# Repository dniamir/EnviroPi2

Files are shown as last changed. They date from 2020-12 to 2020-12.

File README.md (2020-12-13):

# EnvriPi sensor hub shield for Raspberry Pi
A Raspberry Pi shield that houses several different types of sensors
-BME280 - Bosch pressure, temperature and humidity sensor
-BME680 - Bosch pressure, humidity, temperature and VOC sensor
-TMP102 - Texas Instruments temperature sensor
-BMM150 - Bosch magnetometer
-TSL25911FN - Light intensity sensor
-ICM-20649 - Invensense 6-axis IMU (3-axis gyroscope and 3-axis accelerometer)

## Summary
This code utlizies high level functions to communicate with sensors and set their configuration for proper monitoring of an aquarium.

Unfortunately, I can't make the sub-repository for chip communication public. However that package provides a simple interface for communicating with sensors va I2C and SPI.

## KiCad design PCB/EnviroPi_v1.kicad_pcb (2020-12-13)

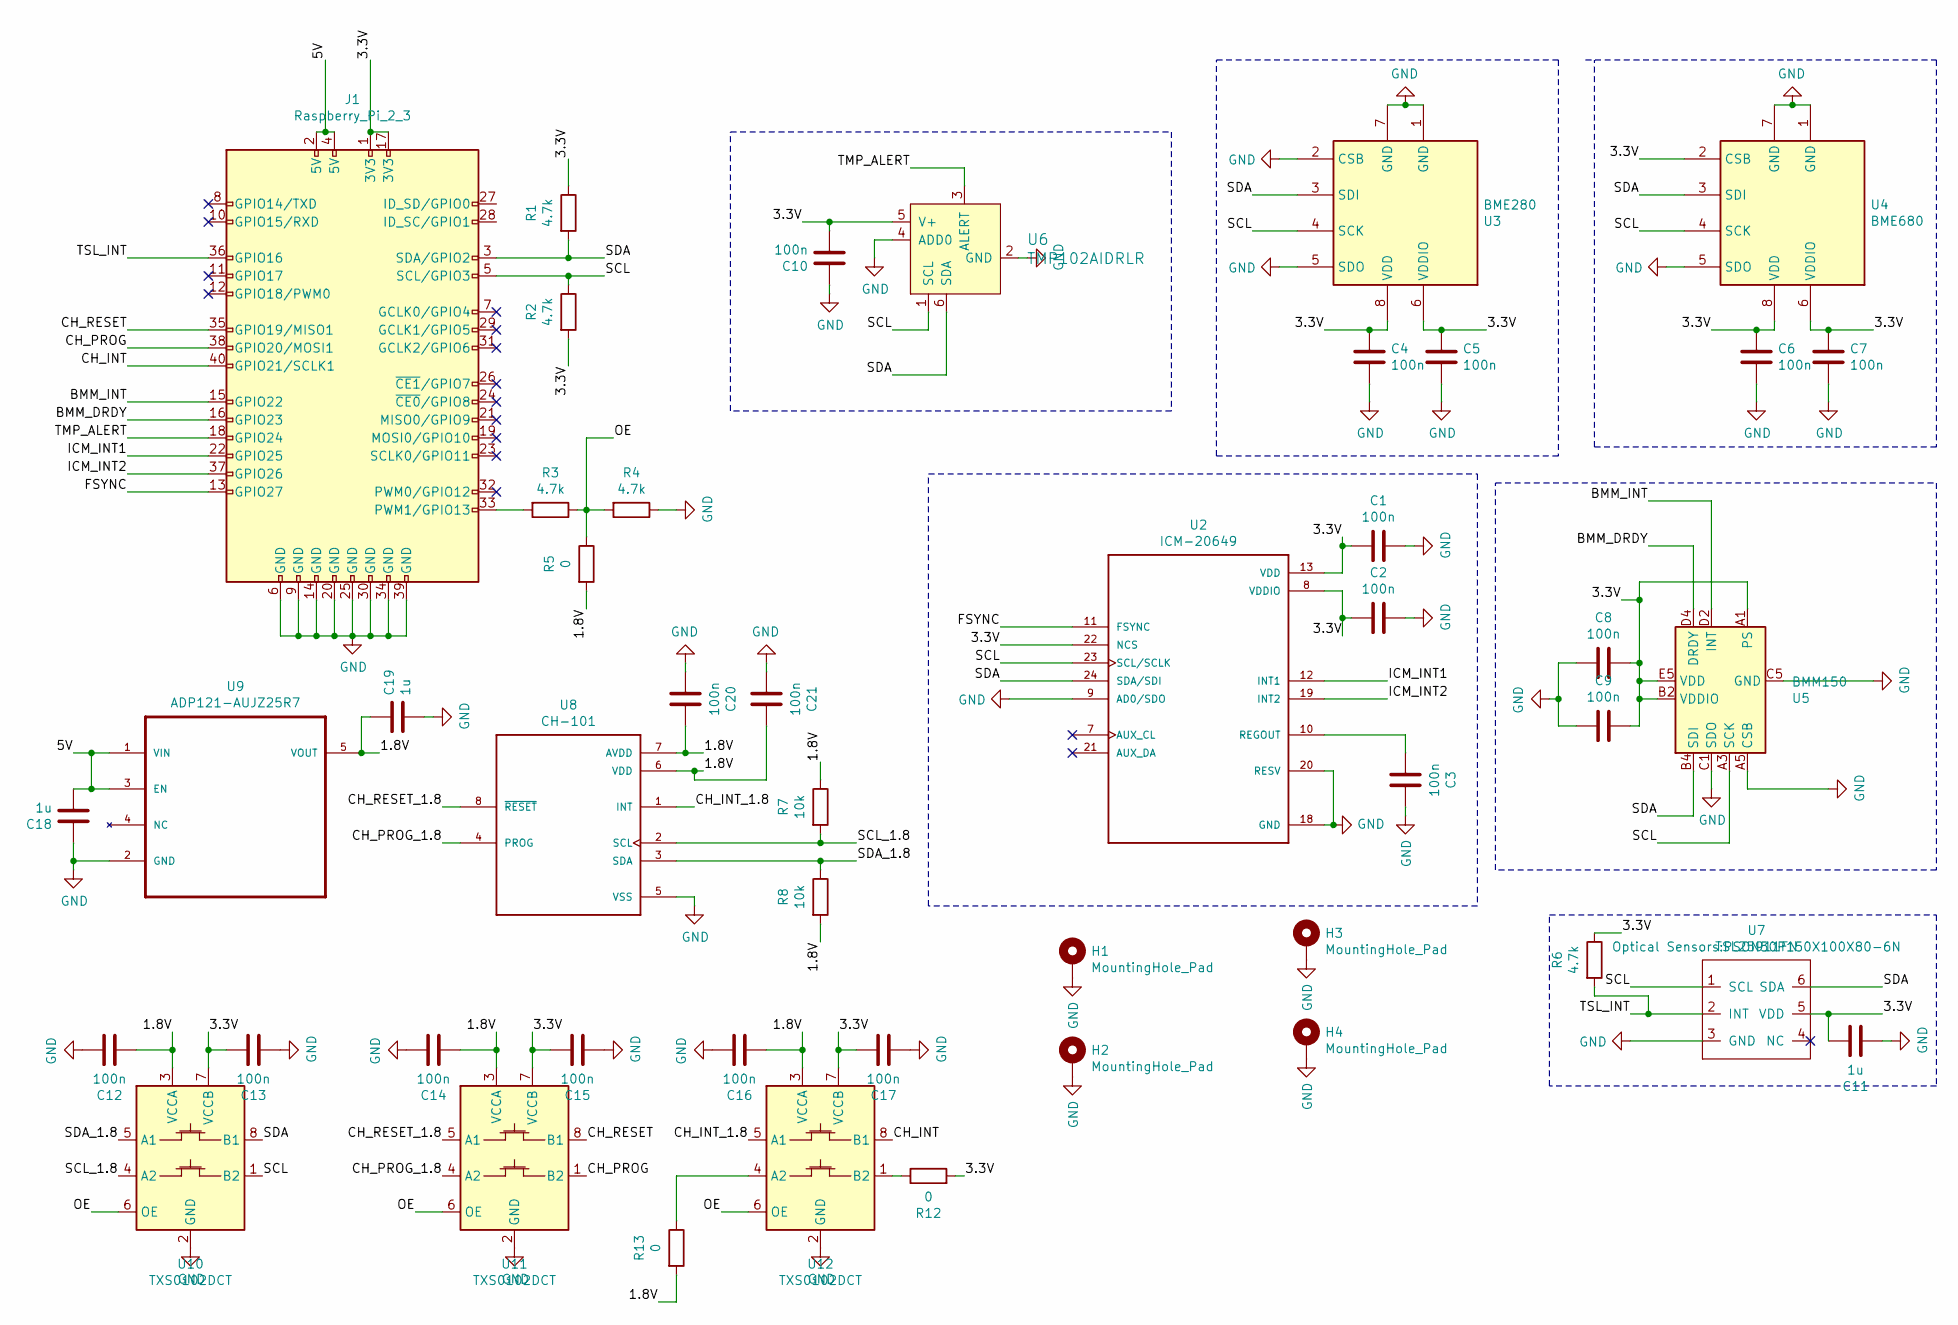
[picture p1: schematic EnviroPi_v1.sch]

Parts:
C1, C2, C3, C4, C5, C6, C7, C8, C9, C10, C12, C13, C14, C15, C16, C17, C20, C21: 100n; C_0805_2012Metric_Pad1.15x1.40mm_HandSolder
C11, C18, C19: 1u; C_0805_2012Metric_Pad1.15x1.40mm_HandSolder
H1, H2, H3, H4: MountingHole_Pad; MountingHole_2.5mm_Pad
J1: Raspberry_Pi_2_3; PinHeader_2x20_P2.54mm_Vertical
R1, R2, R3, R4, R6: 4.7k; R_0805_2012Metric_Pad1.15x1.40mm_HandSolder
R5, R12, R13: 0; R_0805_2012Metric_Pad1.15x1.40mm_HandSolder
R7, R8: 10k; R_0805_2012Metric_Pad1.15x1.40mm_HandSolder
U2: ICM-20649; QFN40P300X300X95-24N
U3: BME280; Bosch_LGA-8_2.5x2.5mm_P0.65mm_ClockwisePinNumbering
U4: BME680; Bosch_LGA-8_3x3mm_P0.8mm_ClockwisePinNumbering
U5: BMM150; WLCSP-12_1.56x1.56mm_P0.4mm
U6: TMP102AIDRLR; SOT50P160X60-6N; MPN TMP102AIDRLR; Digi-Key_PN 296-26834-1-ND
U7: TSL25911FN; PSON50P150X100X80-6N
U8: CH-101; XDCR_CH-101
U9: ADP121-AUJZ25R7; SOT95P280X100-5N
U10, U11, U12: TXS0102DCT; SSOP-8_2.95x2.8mm_P0.65mm

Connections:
/1.8V: C12.1, C14.1, C16.1, C19.1, C20.2, C21.2, R5.2, R7.1, R8.2, R13.2, U8.6 (VDD), U8.7 (AVDD), U9.5 (VOUT), U10.3 (VCCA), U11.3 (VCCA), U12.3 (VCCA)
/3.3V: C1.1, C2.1, C4.1, C5.1, C6.1, C7.1, C8.2, C9.2, C10.2, C11.2, C13.2, C15.2, C17.2, J1.1 (3V3), J1.17 (3V3), R1.1, R2.2, R6.1, R12.2, U2.8 (VDDIO), U2.13 (VDD), U2.22 (NCS), U3.6 (VDDIO), U3.8 (VDD), U4.2 (CSB), U4.6 (VDDIO), U4.8 (VDD), U5.A1 (PS), U5.B2 (VDDIO), U5.E5 (VDD), U6.5 (V+), U7.5 (VDD), U10.7 (VCCB), U11.7 (VCCB), U12.7 (VCCB)
/5V: C18.2, J1.2 (5V), J1.4 (5V), U9.1 (VIN), U9.3 (EN)
/BMM_DRDY: J1.16 (GPIO23), U5.D4 (DRDY)
/BMM_INT: J1.15 (GPIO22), U5.D2 (INT)
/CH_INT: J1.40 (GPIO21/SCLK1), U12.8 (B1)
/CH_INT_1.8: U8.1 (INT), U12.5 (A1)
/CH_PROG: J1.38 (GPIO20/MOSI1), U11.1 (B2)
/CH_PROG_1.8: U8.4 (PROG), U11.4 (A2)
/CH_RESET: J1.35 (GPIO19/MISO1), U11.8 (B1)
/CH_RESET_1.8: U8.8 (~RESET~), U11.5 (A1)
/FSYNC: J1.13 (GPIO27), U2.11 (FSYNC)
/ICM_INT1: J1.22 (GPIO25), U2.12 (INT1)
/ICM_INT2: J1.37 (GPIO26), U2.19 (INT2)
/OE: R3.1, R4.2, R5.1, U10.6 (OE), U11.6 (OE), U12.6 (OE)
/SCL: J1.5 (SCL/GPIO3), R2.1, U2.23 (SCL/SCLK), U3.4 (SCK), U4.4 (SCK), U5.A3 (SCK), U6.1 (SCL), U7.1 (SCL), U10.1 (B2)
/SCL_1.8: R7.2, U8.2 (SCL), U10.4 (A2)
/SDA: J1.3 (SDA/GPIO2), R1.2, U2.24 (SDA/SDI), U3.3 (SDI), U4.3 (SDI), U5.B4 (SDI), U6.6 (SDA), U7.6 (SDA), U10.8 (B1)
/SDA_1.8: R8.1, U8.3 (SDA), U10.5 (A1)
/TMP_ALERT: J1.18 (GPIO24), U6.3 (ALERT)
/TSL_INT: J1.36 (GPIO16), R6.2, U7.2 (INT)
GND: C1.2, C2.2, C3.2, C4.2, C5.2, C6.2, C7.2, C8.1, C9.1, C10.1, C11.1, C12.2, C13.1, C14.2, C15.1, C16.2, C17.1, C18.1, C19.2, C20.1, C21.1, H1.1, H2.1, H3.1, H4.1, J1.6 (GND), J1.9 (GND), J1.14 (GND), J1.20 (GND), J1.25 (GND), J1.30 (GND), J1.34 (GND), J1.39 (GND), R4.1, U2.9 (AD0/SDO), U2.18 (GND), U2.20 (RESV), U3.1 (GND), U3.2 (CSB), U3.5 (SDO), U3.7 (GND), U4.1 (GND), U4.5 (SDO), U4.7 (GND), U5.A5 (CSB), U5.C1 (SDO), U5.C5 (GND), U5.E1 (GND), U5.E3 (GND), U6.2 (GND), U6.4 (ADD0), U7.3 (GND), U8.5 (VSS), U9.2 (GND), U10.2 (GND), U11.2 (GND), U12.2 (GND)
unnamed: C3.1, U2.10 (REGOUT)
unnamed: J1.33 (PWM1/GPIO13), R3.2
unnamed: R12.1, U12.1 (B2)
unnamed: R13.1, U12.4 (A2)

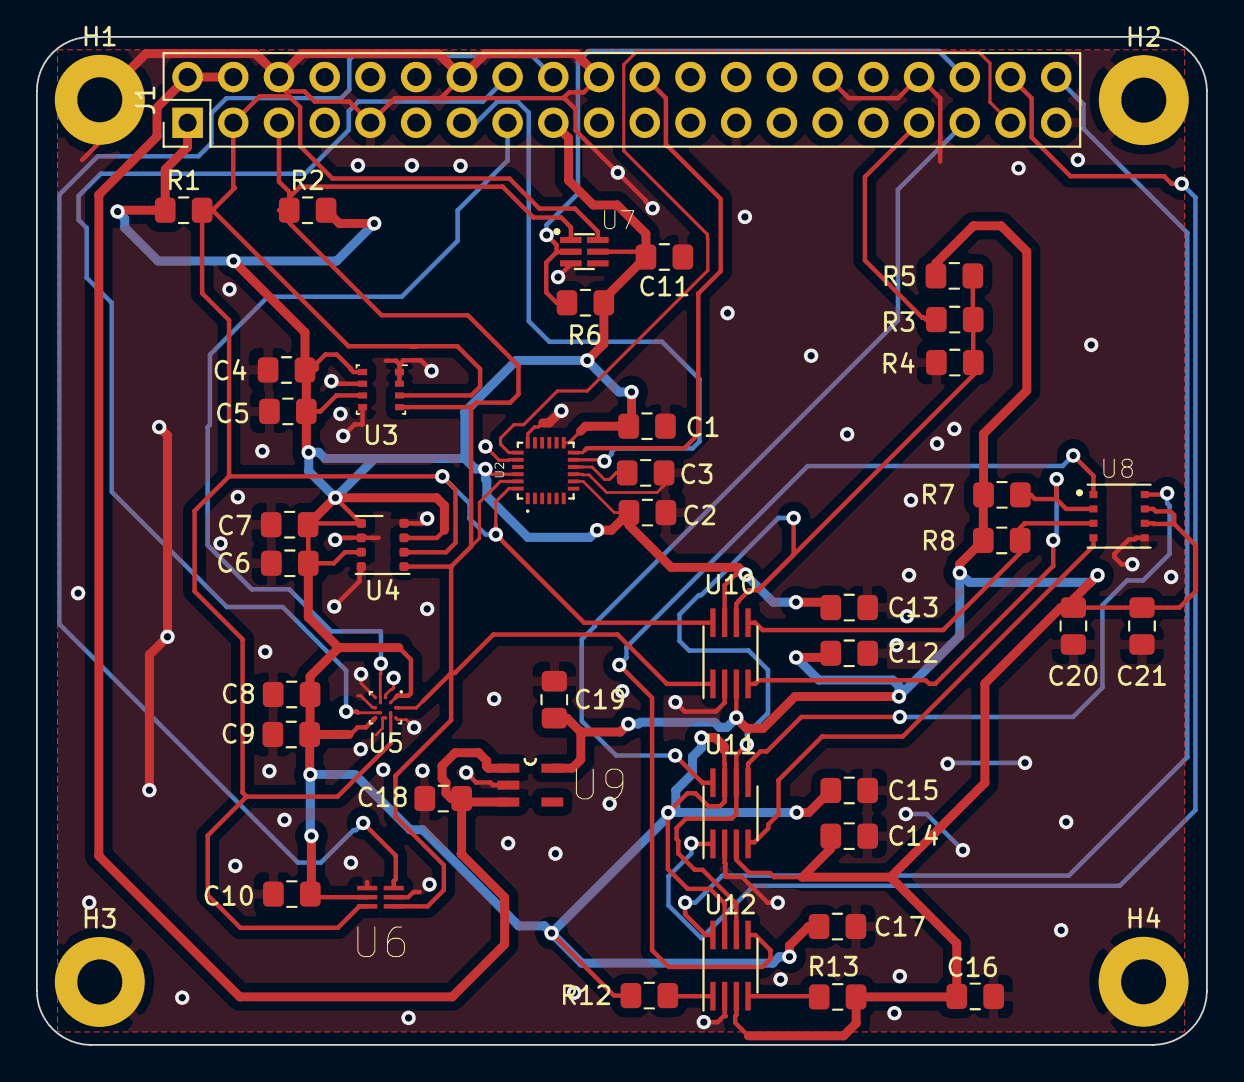
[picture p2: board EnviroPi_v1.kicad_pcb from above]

Board: 2 copper layers, 65.0 x 56.0 mm, 47 parts (0 on the bottom side), 26 nets.

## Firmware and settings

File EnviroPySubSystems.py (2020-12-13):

import time
import numpy
from w1thermsensor import W1ThermSensor
from chip_systems import ProjectSystem
from chip_systems import ADCS
import RPi.GPIO as GPIO
import spidev

import numpy


class AquaPiTemperature(ProjectSystem.ProjectSystem):

	# Connect to Sensor
	# Assuming a single sensor is connected
	# Power is 3.3V
	# Data is connected to GPIO4 (pin 7)

	def __init__(self):
		self.temp_sensor = W1ThermSensor()
		return

	def SetupSystem(self):
		available_sensors = W1ThermSensor.get_available_sensors()
		for available_sensor in available_sensors:
			print(available_sensor)

	def ReadTemperature(self):
		temperature_degc = self.temp_sensor.get_temperature()
		return temperature_degc

	def ReadOutputs(self):
		temperature_degc = self.ReadTemperature()
		return temperature_degc


class AquaPiFluidLevel(ProjectSystem.ProjectSystem):

	def __init__(self):
		spi = spidev.SpiDev()
		spi.open(bus=0, device=0)  # bus=spi_bus, device=CS
		spi.max_speed_hz = 50000
		spi.mode = 0b00

		self.adc = ADCS.Maxim11410(interface=spi)
		self.opc = None
		self.SetupSystem()
		return

	def SetupSystem(self):

		self.adc.WriteRegisters('PD', 0b00)
		self.adc.WriteRegisters('CTRL', 0x26)
		self.adc.WriteRegisters('CAL_START', 0b00000111)

		# Filter
		self.adc.WriteRegisters('LINEF', 0x10)
		self.adc.WriteRegisters('RATE', 0x1111)

		# CNTRL
		self.adc.WriteRegisters('EXTCLK', 0b0)
		self.adc.WriteRegisters('U_BN', 0b0)
		self.adc.WriteRegisters('FORMAT', 0b0)
		self.adc.WriteRegisters('REF_SEL', 0b011)

		# MUX_CTRL0
		self.adc.WriteRegisters('AINP_SEL', 0b0001)
		self.adc.WriteRegisters('AINN_SEL', 0b0000)

		# PGA
		self.adc.WriteRegisters('SIG_PATH', 0b00)
		self.adc.WriteRegisters('GAIN', 0b000)

		# CONV
		self.adc.WriteRegisters('DEST', 0b000)
		self.adc.WriteRegisters('CONV_TYPE', 0b01)

	def TriggerSequence(self):
		self.adc.WriteRegisters(0x02, 0x3A)

	def ReadFluidLevel(self):
		# adc_lsb = self.adc.ReadRegisters('DATA0')[0]
		# self.TriggerSequence()
		# area = numpy.pi * (0.0002 / 2) ** 2
		# adc_lsb *= 1. / 2 ** 23 * 1e3 / 3.7 / area / 133.3 / 64
		adc_bits = 24
		adc_dec = 0
		n_samples = 1
		for i in range(n_samples):
			time.sleep(0.01)
			adc_lsb = self.adc.ReadRegisters('DATA0')[0]
			adc_dec += ProjectSystem.TwosComp(adc_lsb, bits=adc_bits)
		adc_dec = adc_dec / n_samples

		adc_volt_min = 0
		adc_volt_max = 3.3
		adc_lsb_max = 2 ** (adc_bits - 1)
		adc_lsb_min = 0
		# range = adc_volt_max - adc_volt_min
		adc_volts = adc_dec / adc_lsb_max * adc_volt_max

		if self.opc is None:
			self.opc = adc_volts
		adc_volts = adc_volts - self.opc
		fluid_height = (adc_volts + 0.21) / 0.04
		fluid_height = numpy.max([fluid_height, 0])
		return fluid_height

	def ReadOutputs(self):
		fluid_level_cm = self.ReadFluidLevel()
		return fluid_level_cm


class AquaPiPumpSwitches(ProjectSystem.ProjectSystem):

	def __init__(self, switch1_pin=5, switch2_pin=6, pump1_pin=15):
		self.switch1_pin = None
		self.switch2_pin = None
		self.pump1_pin = None
		self.pump1_state = 0
		self.SetupSystem(switch1_pin=switch1_pin,
						 switch2_pin=switch2_pin,
						 pump1_pin=pump1_pin)

	def SetupSystem(self, switch1_pin=5, switch2_pin=6, pump1_pin=15):
		self.switch1_pin = switch1_pin
		self.switch2_pin = switch2_pin
		self.pump1_pin = pump1_pin
		GPIO.setmode(GPIO.BCM)
		GPIO.setup(switch1_pin, GPIO.IN)
		GPIO.setup(switch2_pin, GPIO.IN)
		GPIO.setup(pump1_pin, GPIO.OUT)

		self.pump1_state = 0

	def ReadOutputs(self):
		return self.switch1, self.switch2

	@property
	def switch1(self):
		return GPIO.input(self.switch1_pin)

	@property
	def switch2(self):
		return GPIO.input(self.switch2_pin)

	def StartInPump(self):
		GPIO.output(self.pump1_pin, 1)
		self.pump1_state = 1

	def StopInPump(self):
		GPIO.output(self.pump1_pin, 0)
		self.pump1_state = 0

	#
	# def StopInPump(self):
	# 	GPIO.output(self.pump_in_pin, GPIO.LOW)
	#
	# def StopOutPump(self):
	# 	GPIO.output(self.pump_out_pin, GPIO.LOW)

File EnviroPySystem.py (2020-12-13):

from chip_systems import ProjectSystem
import smbus
import time

from chip_systems import PressureSensors
from chip_systems import TMP102
from chip_systems import TSL2591

class EnviroPy(ProjectSystem.ProjectSystem):

	def __init__(self):
		i2c_bus = smbus.SMBus(1)
		
		self.tmp102 = None
		self.bme680 = None
		self.tsl2592 = None
		
		self.SetupBme(i2c_bus)
		self.SetupTmp(i2c_bus)
		self.SetupTsl(i2c_bus)
		
	def SetupTsl(self, i2c_bus):
		self.tsl2592 = TSL2591.TSL2591(i2c_bus=i2c_bus)
		self.tsl2592.set_gain(0x05)
		self.tsl2592.set_timing(5)
		self.tsl2592.enable()
	
	def SetupTmp(self, i2c_bus):
		self.tmp102 = TMP102.TMP102(i2c_bus=i2c_bus, units='C', address=0x48)
	
	def SetupBme(self, i2c_bus):
		
		self.bme680 = PressureSensors.BME680(interface=i2c_bus)
		self.bme680.WriteRegisters('Reset', 0xB6)
		time.sleep(0.2)
		
		# Read Chip ID
		chip_id = self.bme680.ReadRegisters('Id')
		print('BME Chip ID is %i' % chip_id[0])
		
		self.bme680.WriteRegisters('osrs_h', 0b101)
		self.bme680.WriteRegisters('osrs_t', 0b101)
		self.bme680.WriteRegisters('osrs_p', 0b101)
		
		# Set IIR filter
		self.bme680.WriteRegisters('filter', 0b010)
		
		# Set Gas settings
		self.bme680.WriteRegisters('run_gas', 0b1)
		self.bme680.WriteRegisters('nb_conv', 0b0000)
		
		# Set chip mode
		self.bme680.WriteRegisters('mode', 0b01)
		
	def SetupSystem(self):
		pass

	def ReadOutputs(self):
		pass
